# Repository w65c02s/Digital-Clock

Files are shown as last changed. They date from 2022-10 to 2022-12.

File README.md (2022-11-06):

## Digital Clock

### Introduction 
This is a clock is based on 74xx series TTL logic ICs. The clock pulse is generated by a 32.768kHz crystal which is further divided by divider ICs and a 1Hz pulse is obtained. This pulse is used to drive the seconds, minutes and hour counters. The display is a simple 7 segment LED display driven by 7447 BCD to 7 segment decoder.

The schematics and PCB has been designed in KiCad. This repository contains the complete KiCad project files made in version 6.0 of KiCad.

Refer the documenatation for complete details

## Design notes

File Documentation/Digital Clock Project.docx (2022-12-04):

Digital Clock Project

Introduction

This project is based on the commonly available 74xx series logic ICs. I wanted to build a clock from basic logic gates instead of using a dedicated clock IC. This way wanted to understand digital logic design.

Design

1 Hz clock pulse is generated by a combination of 32Khz crystal, CD4060 (U1) and CD4013 (U2) CMOS ICs. The clock oscillator is built around the CD4060 and 32khz standard clock crystal. 32768 is divided by 14 by the divider built into CD4060. This is further divided by 2 by CD4013 D type flip flop and a 1 Hz pulse is got.

This pulse is fed to the clock input of first decade counter U3 and the output Q3 is fed to the clock input of the second decade counter U5. These two ICs constitute the seconds counter of the clock. The output is fed to two 7447 U4, U6 7 segment decoders which in turn drive the common anode 7 segment displays AFF1, AFF2.

AND Gate U15A is used to detect 60 seconds count and then reset U5 counter and also drive the minutes counter built with U7. The pulse is gated through a OR gate U16A which also has a minutes advance pulse input.

The minutes advance is built with pushbutton SW1 and switch debounce circuit using U17A 74LS14 schmitt trigger inverter.

This minute pulse is fed to the clock input of third decade counter U7 and the output Q3 is fed to the clock input of the fourth decade counter U9. These two ICs constitute the minutes counter of the clock. The output is fed to two 7447 U8, U10 7 segment decoders which in turn drive the common anode 7 segment displays AFF3, AFF4.

AND Gate U15B is used to detect 60 minutes count and then reset U9 counter and also drive the hour counter built with U11. The pulse is gated through a OR gate U16B which also has a hour advance pulse input.

The hour advance is built with pushbutton SW2 and switch debounce circuit using U17B 74LS14 schmitt trigger inverter.

This hour pulse is fed to the clock input of fifth decade counter U11 and the output Q3 is fed to the clock input of the sixth decade counter U13. These two ICs constitute the hour counter of the clock. The output is fed to two 7447 U12, U14 7 segment decoders which in turn drive the common anode 7 segment displays AFF5, AFF6.

AND Gate U15C is used to detect 24 hour count and then reset U13 counter

Seconds blinker is built with transistor T1 which drives two LEDs D3,D4. The input is taken from the 1 Hz clock generator.

The circuit is powered by 5 volts through a Barrel jack connector.

C6 to C22 are power bypass capacitors used to reduce switching noise at logic gates.

The schematics and PCB was designed using opensource Kicad application.

Parts List

Part ID | Description | Quantity

Semiconductors
U1 | CD4060 CMOS 14 stage ripple carry binary counter/divider and oscillator | 1
U2 | CD4013 CMOS Dual D-Type Flip-Flop | 2
U3, U5, U7, U9, U11, U13 | 74LS90 Decade counter | 6
U4, U6, U8, U10, U12, U14 | 74LS47 BCD to 7 segment decoder | 6
U15 | 74LS08 Quad 2-input AND Gate | 1
U16 | 74LS32 Quad 2-input OR Gate | 1
U17 | 74LS14 Hex Schmitt-Trigger Inverters | 1
T1 | 2N2222 NPN transistor | 1
D1, D2 | 1N4148 small signal diode | 2
D3, D4 | Red LED 3mm | 2

Resistors (All ¼ watt)
R1 | 220K ohm resistor | 1
R2 | 10M ohm resistor | 1
R3, R5 | 5.1K ohm resistor | 2
R4, R6 | 2.2K ohm resistor | 2
R7 | 10K ohm resistor | 1
R8, R9, R10, R11, R12, R13, R14, R15, R16, R17, R18, R19, R20, R21, R22, R23, R24, R25, R26, R27, R28, R29, R30, R31, R32, R33, R34, R35, R36, R37, R38, R39, R40, R41, R42, R43, R44, R45, R46, R47, R48, R49 | 220 ohm resistor | 42

Capacitors
C1, C2 | 33pf ceramic capacitor | 2
C3, C4 | 4.7uf electrolytic capacitor | 2
C5 | 10uf electrolytic capacitor | 1
C6, C7, C8, C9, C10, C11, C12, C13, C14, C15, C16, C17, C18, C19, C20, C21, C22 | 0.1uf ceramic capacitor | 17
Miscellaneous
AFF1, AFF2, AFF3, AFF4, AFF5, AFF6 | 7 segment common anode display 0.56 inch | 6
J1 | Barrel Jack 2.1x5.5mm | 1
SW1, SW2 | Tactile switches 6mm | 2
X1 | 32Khz Crystal | 1

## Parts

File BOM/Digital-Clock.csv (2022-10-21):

Source: | E:\Clock Project\Digital-Clock\Digital-Clock.kicad_sch
Date: | 19-10-2022 21:15
Tool: | Eeschema (6.0.8)
Generator: | E:\Program Files\KiCad\6.0\bin\scripting\plugins/bom_csv_grouped_by_value.py
Component Count: | 103
Individual Components:
Item | Qty | Reference(s) | Value | LibPart | Footprint | Datasheet
 |  | AFF1 | LTS-6960HR | Display_Character:LTS-6960HR | Display_7Segment:7SegmentLED_LTS6760_LTS6780 | https://datasheet.octopart.com/LTS-6960HR-Lite-On-datasheet-11803242.pdf
 |  | AFF2 | LTS-6960HR | Display_Character:LTS-6960HR | Display_7Segment:7SegmentLED_LTS6760_LTS6780 | https://datasheet.octopart.com/LTS-6960HR-Lite-On-datasheet-11803242.pdf
 |  | AFF3 | LTS-6960HR | Display_Character:LTS-6960HR | Display_7Segment:7SegmentLED_LTS6760_LTS6780 | https://datasheet.octopart.com/LTS-6960HR-Lite-On-datasheet-11803242.pdf
 |  | AFF4 | LTS-6960HR | Display_Character:LTS-6960HR | Display_7Segment:7SegmentLED_LTS6760_LTS6780 | https://datasheet.octopart.com/LTS-6960HR-Lite-On-datasheet-11803242.pdf
 |  | AFF5 | LTS-6960HR | Display_Character:LTS-6960HR | Display_7Segment:7SegmentLED_LTS6760_LTS6780 | https://datasheet.octopart.com/LTS-6960HR-Lite-On-datasheet-11803242.pdf
 |  | AFF6 | LTS-6960HR | Display_Character:LTS-6960HR | Display_7Segment:7SegmentLED_LTS6760_LTS6780 | https://datasheet.octopart.com/LTS-6960HR-Lite-On-datasheet-11803242.pdf
 |  | C1 | 39p | Device:C | Capacitor_THT:C_Disc_D5.0mm_W2.5mm_P2.50mm | ~
 |  | C2 | 39p | Device:C | Capacitor_THT:C_Disc_D5.0mm_W2.5mm_P2.50mm | ~
 |  | C3 | 4.7u | Digital-Clock-rescue:CP-Device | Capacitor_THT:CP_Radial_D5.0mm_P2.50mm
 |  | C4 | 4.7u | Digital-Clock-rescue:CP-Device | Capacitor_THT:CP_Radial_D5.0mm_P2.50mm
 |  | C5 | 10u | Digital-Clock-rescue:CP-Device | Capacitor_THT:CP_Radial_D5.0mm_P2.50mm
 |  | C6 | 0.1u | Device:C | Capacitor_THT:C_Disc_D5.0mm_W2.5mm_P2.50mm | ~
 |  | C7 | 0.1u | Device:C | Capacitor_THT:C_Disc_D5.0mm_W2.5mm_P2.50mm | ~
 |  | C8 | 0.1u | Device:C | Capacitor_THT:C_Disc_D5.0mm_W2.5mm_P2.50mm | ~
 |  | C9 | 0.1u | Device:C | Capacitor_THT:C_Disc_D5.0mm_W2.5mm_P2.50mm | ~
 |  | C10 | 0.1u | Device:C | Capacitor_THT:C_Disc_D5.0mm_W2.5mm_P2.50mm | ~
 |  | C11 | 0.1u | Device:C | Capacitor_THT:C_Disc_D5.0mm_W2.5mm_P2.50mm | ~
 |  | C12 | 0.1u | Device:C | Capacitor_THT:C_Disc_D5.0mm_W2.5mm_P2.50mm | ~
 |  | C13 | 0.1u | Device:C | Capacitor_THT:C_Disc_D5.0mm_W2.5mm_P2.50mm | ~
 |  | C14 | 0.1u | Device:C | Capacitor_THT:C_Disc_D5.0mm_W2.5mm_P2.50mm | ~
 |  | C15 | 0.1u | Device:C | Capacitor_THT:C_Disc_D5.0mm_W2.5mm_P2.50mm | ~
 |  | C16 | 0.1u | Device:C | Capacitor_THT:C_Disc_D5.0mm_W2.5mm_P2.50mm | ~
 |  | C17 | 0.1u | Device:C | Capacitor_THT:C_Disc_D5.0mm_W2.5mm_P2.50mm | ~
 |  | C18 | 0.1u | Device:C | Capacitor_THT:C_Disc_D5.0mm_W2.5mm_P2.50mm | ~
 |  | C19 | 0.1u | Device:C | Capacitor_THT:C_Disc_D5.0mm_W2.5mm_P2.50mm | ~
 |  | C20 | 0.1u | Device:C | Capacitor_THT:C_Disc_D5.0mm_W2.5mm_P2.50mm | ~
 |  | C21 | 0.1u | Device:C | Capacitor_THT:C_Disc_D5.0mm_W2.5mm_P2.50mm | ~
 |  | C22 | 0.1u | Device:C | Capacitor_THT:C_Disc_D5.0mm_W2.5mm_P2.50mm | ~
 |  | D1 | 1N4148 | Diode:1N4148 | Diode_THT:D_DO-35_SOD27_P7.62mm_Horizontal | https://assets.nexperia.com/documents/data-sheet/1N4148_1N4448.pdf
 |  | D2 | 1N4148 | Diode:1N4148 | Diode_THT:D_DO-35_SOD27_P7.62mm_Horizontal | https://assets.nexperia.com/documents/data-sheet/1N4148_1N4448.pdf
 |  | D3 | LED | Device:LED | LED_THT:LED_D3.0mm | ~
 |  | D4 | LED | Device:LED | LED_THT:LED_D3.0mm | ~
 |  | J1 | Barrel_Jack_MountingPin | Connector:Barrel_Jack_MountingPin | Connector_BarrelJack:BarrelJack_CUI_PJ-063AH_Horizontal | ~
 |  | R1 | 220K | Device:R | Resistor_THT:R_Axial_DIN0207_L6.3mm_D2.5mm_P10.16mm_Horizontal | ~
 |  | R2 | 10M | Device:R | Resistor_THT:R_Axial_DIN0207_L6.3mm_D2.5mm_P10.16mm_Horizontal | ~
 |  | R3 | 5K | Device:R | Resistor_THT:R_Axial_DIN0207_L6.3mm_D2.5mm_P10.16mm_Horizontal | ~
 |  | R4 | 2.2K | Device:R | Resistor_THT:R_Axial_DIN0207_L6.3mm_D2.5mm_P10.16mm_Horizontal | ~
 |  | R5 | 5K | Device:R | Resistor_THT:R_Axial_DIN0207_L6.3mm_D2.5mm_P10.16mm_Horizontal | ~
 |  | R6 | 2.2K | Device:R | Resistor_THT:R_Axial_DIN0207_L6.3mm_D2.5mm_P10.16mm_Horizontal | ~
 |  | R7 | 10K | Device:R | Resistor_THT:R_Axial_DIN0207_L6.3mm_D2.5mm_P10.16mm_Horizontal | ~
 |  | R8 | 220 | Device:R | Resistor_THT:R_Axial_DIN0207_L6.3mm_D2.5mm_P10.16mm_Horizontal | ~
 |  | R9 | 220 | Device:R | Resistor_THT:R_Axial_DIN0207_L6.3mm_D2.5mm_P10.16mm_Horizontal | ~
 |  | R10 | 220 | Device:R | Resistor_THT:R_Axial_DIN0207_L6.3mm_D2.5mm_P10.16mm_Horizontal | ~
 |  | R11 | 220 | Device:R | Resistor_THT:R_Axial_DIN0207_L6.3mm_D2.5mm_P10.16mm_Horizontal | ~
 |  | R12 | 220 | Device:R | Resistor_THT:R_Axial_DIN0207_L6.3mm_D2.5mm_P10.16mm_Horizontal | ~
 |  | R13 | 220 | Device:R | Resistor_THT:R_Axial_DIN0207_L6.3mm_D2.5mm_P10.16mm_Horizontal | ~
 |  | R14 | 220 | Device:R | Resistor_THT:R_Axial_DIN0207_L6.3mm_D2.5mm_P10.16mm_Horizontal | ~
 |  | R15 | 220 | Device:R | Resistor_THT:R_Axial_DIN0207_L6.3mm_D2.5mm_P10.16mm_Horizontal | ~
 |  | R16 | 220 | Device:R | Resistor_THT:R_Axial_DIN0207_L6.3mm_D2.5mm_P10.16mm_Horizontal | ~
 |  | R17 | 220 | Device:R | Resistor_THT:R_Axial_DIN0207_L6.3mm_D2.5mm_P10.16mm_Horizontal | ~
 |  | R18 | 220 | Device:R | Resistor_THT:R_Axial_DIN0207_L6.3mm_D2.5mm_P10.16mm_Horizontal | ~
 |  | R19 | 220 | Device:R | Resistor_THT:R_Axial_DIN0207_L6.3mm_D2.5mm_P10.16mm_Horizontal | ~
 |  | R20 | 220 | Device:R | Resistor_THT:R_Axial_DIN0207_L6.3mm_D2.5mm_P10.16mm_Horizontal | ~
 |  | R21 | 220 | Device:R | Resistor_THT:R_Axial_DIN0207_L6.3mm_D2.5mm_P10.16mm_Horizontal | ~
 |  | R22 | 220 | Device:R | Resistor_THT:R_Axial_DIN0207_L6.3mm_D2.5mm_P10.16mm_Horizontal | ~
 |  | R23 | 220 | Device:R | Resistor_THT:R_Axial_DIN0207_L6.3mm_D2.5mm_P10.16mm_Horizontal | ~
 |  | R24 | 220 | Device:R | Resistor_THT:R_Axial_DIN0207_L6.3mm_D2.5mm_P10.16mm_Horizontal | ~
 |  | R25 | 220 | Device:R | Resistor_THT:R_Axial_DIN0207_L6.3mm_D2.5mm_P10.16mm_Horizontal | ~
 |  | R26 | 220 | Device:R | Resistor_THT:R_Axial_DIN0207_L6.3mm_D2.5mm_P10.16mm_Horizontal | ~
 |  | R27 | 220 | Device:R | Resistor_THT:R_Axial_DIN0207_L6.3mm_D2.5mm_P10.16mm_Horizontal | ~
 |  | R28 | 220 | Device:R | Resistor_THT:R_Axial_DIN0207_L6.3mm_D2.5mm_P10.16mm_Horizontal | ~
 |  | R29 | 220 | Device:R | Resistor_THT:R_Axial_DIN0207_L6.3mm_D2.5mm_P10.16mm_Horizontal | ~
 |  | R30 | 220 | Device:R | Resistor_THT:R_Axial_DIN0207_L6.3mm_D2.5mm_P10.16mm_Horizontal | ~
 |  | R31 | 220 | Device:R | Resistor_THT:R_Axial_DIN0207_L6.3mm_D2.5mm_P10.16mm_Horizontal | ~
 |  | R32 | 220 | Device:R | Resistor_THT:R_Axial_DIN0207_L6.3mm_D2.5mm_P10.16mm_Horizontal | ~
 |  | R33 | 220 | Device:R | Resistor_THT:R_Axial_DIN0207_L6.3mm_D2.5mm_P10.16mm_Horizontal | ~
 |  | R34 | 220 | Device:R | Resistor_THT:R_Axial_DIN0207_L6.3mm_D2.5mm_P10.16mm_Horizontal | ~
 |  | R35 | 220 | Device:R | Resistor_THT:R_Axial_DIN0207_L6.3mm_D2.5mm_P10.16mm_Horizontal | ~
 |  | R36 | 220 | Device:R | Resistor_THT:R_Axial_DIN0207_L6.3mm_D2.5mm_P10.16mm_Horizontal | ~
 |  | R37 | 220 | Device:R | Resistor_THT:R_Axial_DIN0207_L6.3mm_D2.5mm_P10.16mm_Horizontal | ~
 |  | R38 | 220 | Device:R | Resistor_THT:R_Axial_DIN0207_L6.3mm_D2.5mm_P10.16mm_Horizontal | ~
 |  | R39 | 220 | Device:R | Resistor_THT:R_Axial_DIN0207_L6.3mm_D2.5mm_P10.16mm_Horizontal | ~
 |  | R40 | 220 | Device:R | Resistor_THT:R_Axial_DIN0207_L6.3mm_D2.5mm_P10.16mm_Horizontal | ~
 |  | R41 | 220 | Device:R | Resistor_THT:R_Axial_DIN0207_L6.3mm_D2.5mm_P10.16mm_Horizontal | ~
 |  | R42 | 220 | Device:R | Resistor_THT:R_Axial_DIN0207_L6.3mm_D2.5mm_P10.16mm_Horizontal | ~
 |  | R43 | 220 | Device:R | Resistor_THT:R_Axial_DIN0207_L6.3mm_D2.5mm_P10.16mm_Horizontal | ~
 |  | R44 | 220 | Device:R | Resistor_THT:R_Axial_DIN0207_L6.3mm_D2.5mm_P10.16mm_Horizontal | ~
 |  | R45 | 220 | Device:R | Resistor_THT:R_Axial_DIN0207_L6.3mm_D2.5mm_P10.16mm_Horizontal | ~
 |  | R46 | 220 | Device:R | Resistor_THT:R_Axial_DIN0207_L6.3mm_D2.5mm_P10.16mm_Horizontal | ~
 |  | R47 | 220 | Device:R | Resistor_THT:R_Axial_DIN0207_L6.3mm_D2.5mm_P10.16mm_Horizontal | ~
 |  | R48 | 220 | Device:R | Resistor_THT:R_Axial_DIN0207_L6.3mm_D2.5mm_P10.16mm_Horizontal | ~
 |  | R49 | 220 | Device:R | Resistor_THT:R_Axial_DIN0207_L6.3mm_D2.5mm_P10.16mm_Horizontal | ~
 |  | SW1 | SW_Push | Switch:SW_Push | Button_Switch_THT:SW_PUSH_6mm | ~
 |  | SW2 | SW_Push | Switch:SW_Push | Button_Switch_THT:SW_PUSH_6mm | ~
 |  | T1 | 2N2222 | Transistor_BJT:2N2219 | Package_TO_SOT_THT:TO-92 | http://www.onsemi.com/pub_link/Collateral/2N2219-D.PDF
 |  | U1 | CD4060 | Digital-Clock-rescue:CD4060-CD4060 | Package_DIP:DIP-16_W7.62mm | DOCUMENTATION
 |  | U2 | 4013 | 4xxx:4013 | Package_DIP:DIP-14_W7.62mm | http://www.onsemi.com/pub/Collateral/MC14013B-D.PDF
 |  | U3 | 74LS90 | 74xx:74LS90 | Package_DIP:DIP-14_W7.62mm | http://www.ti.com/lit/gpn/sn74LS90
 |  | U4 | 74LS47 | 74xx:74LS47 | Package_DIP:DIP-16_W7.62mm | http://www.ti.com/lit/gpn/sn74LS47
 |  | U5 | 74LS90 | 74xx:74LS90 | Package_DIP:DIP-14_W7.62mm | http://www.ti.com/lit/gpn/sn74LS90
 |  | U6 | 74LS47 | 74xx:74LS47 | Package_DIP:DIP-16_W7.62mm | http://www.ti.com/lit/gpn/sn74LS47
 |  | U7 | 74LS90 | 74xx:74LS90 | Package_DIP:DIP-14_W7.62mm | http://www.ti.com/lit/gpn/sn74LS90
 |  | U8 | 74LS47 | 74xx:74LS47 | Package_DIP:DIP-16_W7.62mm | http://www.ti.com/lit/gpn/sn74LS47
 |  | U9 | 74LS90 | 74xx:74LS90 | Package_DIP:DIP-14_W7.62mm | http://www.ti.com/lit/gpn/sn74LS90
 |  | U10 | 74LS47 | 74xx:74LS47 | Package_DIP:DIP-16_W7.62mm | http://www.ti.com/lit/gpn/sn74LS47
 |  | U11 | 74LS90 | 74xx:74LS90 | Package_DIP:DIP-14_W7.62mm | http://www.ti.com/lit/gpn/sn74LS90
 |  | U12 | 74LS47 | 74xx:74LS47 | Package_DIP:DIP-16_W7.62mm | http://www.ti.com/lit/gpn/sn74LS47
 |  | U13 | 74LS90 | 74xx:74LS90 | Package_DIP:DIP-14_W7.62mm | http://www.ti.com/lit/gpn/sn74LS90
 |  | U14 | 74LS47 | 74xx:74LS47 | Package_DIP:DIP-16_W7.62mm | http://www.ti.com/lit/gpn/sn74LS47
 |  | U15 | 74LS08 | 74xx:74LS08 | Package_DIP:DIP-14_W7.62mm | http://www.ti.com/lit/gpn/sn74LS08
 |  | U16 | 74LS32 | 74xx:74LS32 | Package_DIP:DIP-14_W7.62mm | http://www.ti.com/lit/gpn/sn74LS32
 |  | U17 | 74LS14 | 74xx:74LS14 | Package_DIP:DIP-14_W7.62mm | http://www.ti.com/lit/gpn/sn74LS14
 |  | X1 | 32Khz | Device:Crystal | Crystal:Crystal_Round_D1.0mm_Vertical | ~
Collated Components:
Item | Qty | Reference(s) | Value | LibPart | Footprint | Datasheet
1 | 6 | AFF1, AFF2, AFF3, AFF4, AFF5, AFF6 | LTS-6960HR | Display_Character:LTS-6960HR | Display_7Segment:7SegmentLED_LTS6760_LTS6780 | https://datasheet.octopart.com/LTS-6960HR-Lite-On-datasheet-11803242.pdf
2 | 2 | C1, C2 | 39p | Device:C | Capacitor_THT:C_Disc_D5.0mm_W2.5mm_P2.50mm | ~
3 | 2 | C3, C4 | 4.7u | Digital-Clock-rescue:CP-Device | Capacitor_THT:CP_Radial_D5.0mm_P2.50mm
4 | 1 | C5 | 10u | Digital-Clock-rescue:CP-Device | Capacitor_THT:CP_Radial_D5.0mm_P2.50mm
5 | 17 | C6, C7, C8, C9, C10, C11, C12, C13, C14, C15, C16, C17, C18, C19, C20, C21, C22 | 0.1u | Device:C | Capacitor_THT:C_Disc_D5.0mm_W2.5mm_P2.50mm | ~
6 | 2 | D1, D2 | 1N4148 | Diode:1N4148 | Diode_THT:D_DO-35_SOD27_P7.62mm_Horizontal | https://assets.nexperia.com/documents/data-sheet/1N4148_1N4448.pdf
7 | 2 | D3, D4 | LED | Device:LED | LED_THT:LED_D3.0mm | ~
8 | 1 | J1 | Barrel_Jack_MountingPin | Connector:Barrel_Jack_MountingPin | Connector_BarrelJack:BarrelJack_CUI_PJ-063AH_Horizontal | ~
9 | 1 | R1 | 220K | Device:R | Resistor_THT:R_Axial_DIN0207_L6.3mm_D2.5mm_P10.16mm_Horizontal | ~
10 | 1 | R2 | 10M | Device:R | Resistor_THT:R_Axial_DIN0207_L6.3mm_D2.5mm_P10.16mm_Horizontal | ~
11 | 2 | R3, R5 | 5K | Device:R | Resistor_THT:R_Axial_DIN0207_L6.3mm_D2.5mm_P10.16mm_Horizontal | ~
12 | 2 | R4, R6 | 2.2K | Device:R | Resistor_THT:R_Axial_DIN0207_L6.3mm_D2.5mm_P10.16mm_Horizontal | ~
13 | 1 | R7 | 10K | Device:R | Resistor_THT:R_Axial_DIN0207_L6.3mm_D2.5mm_P10.16mm_Horizontal | ~
14 | 42 | R8, R9, R10, R11, R12, R13, R14, R15, R16, R17, R18, R19, R20, R21, R22, R23, R24, R25, R26, R27, R28, R29, R30, R31, R32, R33, R34, R35, R36, R37, R38, R39, R40, R41, R42, R43, R44, R45, R46, R47, R48, R49 | 220 | Device:R | Resistor_THT:R_Axial_DIN0207_L6.3mm_D2.5mm_P10.16mm_Horizontal | ~
15 | 2 | SW1, SW2 | SW_Push | Switch:SW_Push | Button_Switch_THT:SW_PUSH_6mm | ~
16 | 1 | T1 | 2N2222 | Transistor_BJT:2N2219 | Package_TO_SOT_THT:TO-92 | http://www.onsemi.com/pub_link/Collateral/2N2219-D.PDF
17 | 1 | U1 | CD4060 | Digital-Clock-rescue:CD4060-CD4060 | Package_DIP:DIP-16_W7.62mm | DOCUMENTATION
18 | 1 | U2 | 4013 | 4xxx:4013 | Package_DIP:DIP-14_W7.62mm | http://www.onsemi.com/pub/Collateral/MC14013B-D.PDF
19 | 6 | U3, U5, U7, U9, U11, U13 | 74LS90 | 74xx:74LS90 | Package_DIP:DIP-14_W7.62mm | http://www.ti.com/lit/gpn/sn74LS90
20 | 6 | U4, U6, U8, U10, U12, U14 | 74LS47 | 74xx:74LS47 | Package_DIP:DIP-16_W7.62mm | http://www.ti.com/lit/gpn/sn74LS47
21 | 1 | U15 | 74LS08 | 74xx:74LS08 | Package_DIP:DIP-14_W7.62mm | http://www.ti.com/lit/gpn/sn74LS08
22 | 1 | U16 | 74LS32 | 74xx:74LS32 | Package_DIP:DIP-14_W7.62mm | http://www.ti.com/lit/gpn/sn74LS32
23 | 1 | U17 | 74LS14 | 74xx:74LS14 | Package_DIP:DIP-14_W7.62mm | http://www.ti.com/lit/gpn/sn74LS14
24 | 1 | X1 | 32Khz | Device:Crystal | Crystal:Crystal_Round_D1.0mm_Vertical | ~

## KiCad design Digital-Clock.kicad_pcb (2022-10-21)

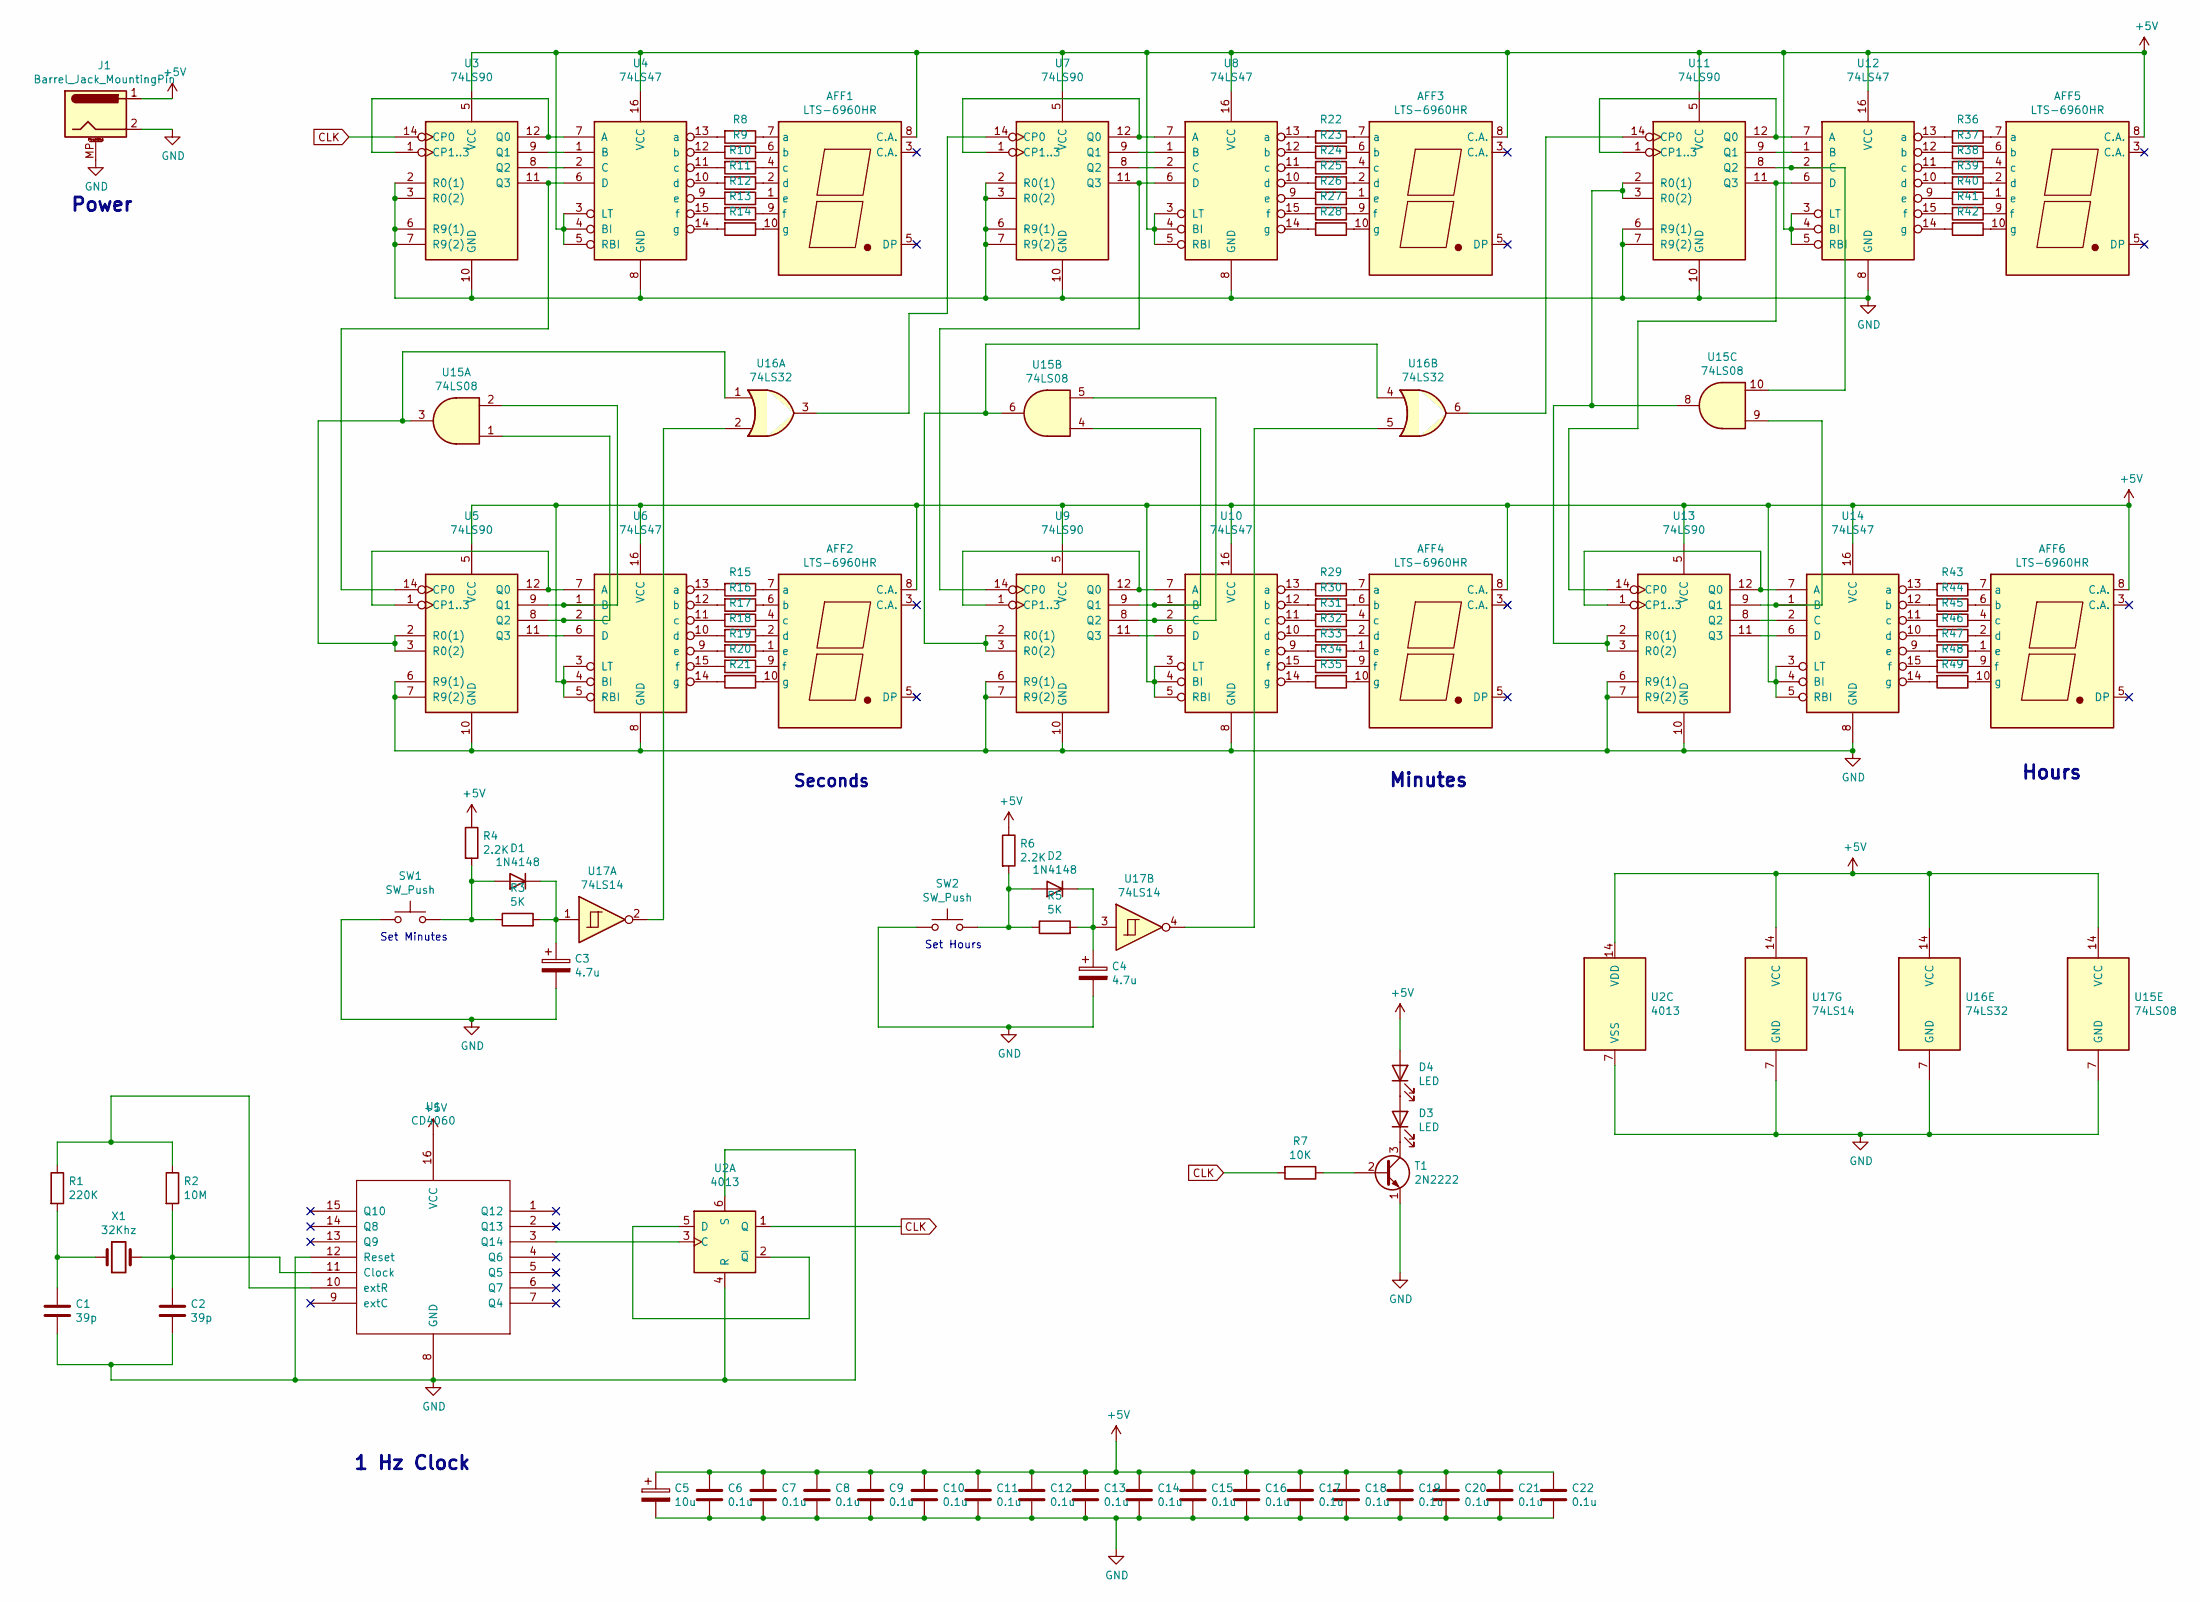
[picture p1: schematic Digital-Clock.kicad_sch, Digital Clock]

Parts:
AFF1, AFF2, AFF3, AFF4, AFF5, AFF6: LTS-6960HR; 7SegmentLED_LTS6760_LTS6780
C1, C2: 39p; C_Disc_D5.0mm_W2.5mm_P2.50mm
C3, C4: 4.7u; CP_Radial_D5.0mm_P2.50mm
C5: 10u; CP_Radial_D5.0mm_P2.50mm
C6, C7, C8, C9, C10, C11, C12, C13, C14, C15, C16, C17, C18, C19, C20, C21, C22: 0.1u; C_Disc_D5.0mm_W2.5mm_P2.50mm
D1, D2: 1N4148; D_DO-35_SOD27_P7.62mm_Horizontal
D3, D4: LED; LED_D3.0mm
J1: Barrel_Jack_MountingPin; BarrelJack_CUI_PJ-063AH_Horizontal
R1: 220K; R_Axial_DIN0207_L6.3mm_D2.5mm_P10.16mm_Horizontal
R2: 10M; R_Axial_DIN0207_L6.3mm_D2.5mm_P10.16mm_Horizontal
R3, R5: 5K; R_Axial_DIN0207_L6.3mm_D2.5mm_P10.16mm_Horizontal
R4, R6: 2.2K; R_Axial_DIN0207_L6.3mm_D2.5mm_P10.16mm_Horizontal
R7: 10K; R_Axial_DIN0207_L6.3mm_D2.5mm_P10.16mm_Horizontal
R8, R9, R10, R11, R12, R13, R14, R15, R16, R17, R18, R19, R20, R21, R22, R23, R24, R25, R26, R27, R28, R29, R30, R31, R32, R33, R34, R35, R36, R37, R38, R39, R40, R41, R42, R43, R44, R45, R46, R47, R48, R49: 220; R_Axial_DIN0207_L6.3mm_D2.5mm_P10.16mm_Horizontal
SW1, SW2: SW_Push; SW_PUSH_6mm
T1: 2N2222; TO-92
U1: CD4060; DIP-16_W7.62mm
U2: 4013; DIP-14_W7.62mm
U3, U5, U7, U9, U11, U13: 74LS90; DIP-14_W7.62mm
U4, U6, U8, U10, U12, U14: 74LS47; DIP-16_W7.62mm
U15: 74LS08; DIP-14_W7.62mm
U16: 74LS32; DIP-14_W7.62mm
U17: 74LS14; DIP-14_W7.62mm
X1: 32Khz; Crystal_Round_D1.0mm_Vertical

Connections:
+5V: AFF1.8 (C.A.), AFF2.8 (C.A.), AFF3.8 (C.A.), AFF4.8 (C.A.), AFF5.8 (C.A.), AFF6.8 (C.A.), C5.1, C6.1, C7.1, C8.1, C9.1, C10.1, C11.1, C12.1, C13.1, C14.1, C15.1, C16.1, C17.1, C18.1, C19.1, C20.1, C21.1, C22.1, D4.2 (A), J1.1, R4.1, R6.1, U1.16 (VCC), U2.14 (VDD), U3.5 (VCC), U4.3 (LT), U4.4 (BI), U4.5 (RBI), U4.16 (VCC), U5.5 (VCC), U6.3 (LT), U6.4 (BI), U6.5 (RBI), U6.16 (VCC), U7.5 (VCC), U8.3 (LT), U8.4 (BI), U8.5 (RBI), U8.16 (VCC), U9.5 (VCC), U10.3 (LT), U10.4 (BI), U10.5 (RBI), U10.16 (VCC), U11.5 (VCC), U12.3 (LT), U12.4 (BI), U12.5 (RBI), U12.16 (VCC), U13.5 (VCC), U14.3 (LT), U14.4 (BI), U14.5 (RBI), U14.16 (VCC), U15.14 (VCC), U16.14 (VCC), U17.14 (VCC)
CLK: R7.2, U2.1 (Q), U3.14 (CP0)
GND: C1.2, C2.2, C3.2, C4.2, C5.2, C6.2, C7.2, C8.2, C9.2, C10.2, C11.2, C12.2, C13.2, C14.2, C15.2, C16.2, C17.2, C18.2, C19.2, C20.2, C21.2, C22.2, J1.2, J1.MP (MountPin), SW1.1, SW2.1, T1.1 (E), U1.8 (GND), U1.12 (Reset), U2.4 (R), U2.6 (S), U2.7 (VSS), U3.2 (R0(1)), U3.3 (R0(2)), U3.6 (R9(1)), U3.7 (R9(2)), U3.10 (GND), U4.8 (GND), U5.6 (R9(1)), U5.7 (R9(2)), U5.10 (GND), U6.8 (GND), U7.2 (R0(1)), U7.3 (R0(2)), U7.6 (R9(1)), U7.7 (R9(2)), U7.10 (GND), U8.8 (GND), U9.6 (R9(1)), U9.7 (R9(2)), U9.10 (GND), U10.8 (GND), U11.6 (R9(1)), U11.7 (R9(2)), U11.10 (GND), U12.8 (GND), U13.6 (R9(1)), U13.7 (R9(2)), U13.10 (GND), U14.8 (GND), U15.7 (GND), U16.7 (GND), U17.7 (GND)
unnamed: AFF1.1 (e), R12.1
unnamed: AFF1.2 (d), R11.1
unnamed: AFF1.4 (c), R10.1
unnamed: AFF1.6 (b), R9.1
unnamed: AFF1.7 (a), R8.1
unnamed: AFF1.9 (f), R13.1
unnamed: AFF1.10 (g), R14.1
unnamed: AFF2.1 (e), R19.1
unnamed: AFF2.2 (d), R18.1
unnamed: AFF2.4 (c), R17.1
unnamed: AFF2.6 (b), R16.1
unnamed: AFF2.7 (a), R15.1
unnamed: AFF2.9 (f), R20.1
unnamed: AFF2.10 (g), R21.1
unnamed: AFF3.1 (e), R26.1
unnamed: AFF3.2 (d), R25.1
unnamed: AFF3.4 (c), R24.1
unnamed: AFF3.6 (b), R23.1
unnamed: AFF3.7 (a), R22.1
unnamed: AFF3.9 (f), R27.1
unnamed: AFF3.10 (g), R28.1
unnamed: AFF4.1 (e), R33.1
unnamed: AFF4.2 (d), R32.1
unnamed: AFF4.4 (c), R31.1
unnamed: AFF4.6 (b), R30.1
unnamed: AFF4.7 (a), R29.1
unnamed: AFF4.9 (f), R34.1
unnamed: AFF4.10 (g), R35.1
unnamed: AFF5.1 (e), R40.1
unnamed: AFF5.2 (d), R39.1
unnamed: AFF5.4 (c), R38.1
unnamed: AFF5.6 (b), R37.1
unnamed: AFF5.7 (a), R36.1
unnamed: AFF5.9 (f), R41.1
unnamed: AFF5.10 (g), R42.1
unnamed: AFF6.1 (e), R47.1
unnamed: AFF6.2 (d), R46.1
unnamed: AFF6.4 (c), R45.1
unnamed: AFF6.6 (b), R44.1
unnamed: AFF6.7 (a), R43.1
unnamed: AFF6.9 (f), R48.1
unnamed: AFF6.10 (g), R49.1
unnamed: C1.1, R1.2, X1.1
unnamed: C2.1, R2.2, U1.11 (Clock), X1.2
unnamed: C3.1, D1.1 (K), R3.2, U17.1
unnamed: C4.1, D2.1 (K), R5.2, U17.3
unnamed: D1.2 (A), R3.1, R4.2, SW1.2
unnamed: D2.2 (A), R5.1, R6.2, SW2.2
unnamed: D3.1 (K), T1.3 (C)
unnamed: D3.2 (A), D4.1 (K)
unnamed: R1.1, R2.1, U1.10 (extR)
unnamed: R7.1, T1.2 (B)
unnamed: R8.2, U4.13 (a)
unnamed: R9.2, U4.12 (b)
unnamed: R10.2, U4.11 (c)
unnamed: R11.2, U4.10 (d)
unnamed: R12.2, U4.9 (e)
unnamed: R13.2, U4.15 (f)
unnamed: R14.2, U4.14 (g)
unnamed: R15.2, U6.13 (a)
unnamed: R16.2, U6.12 (b)
unnamed: R17.2, U6.11 (c)
unnamed: R18.2, U6.10 (d)
unnamed: R19.2, U6.9 (e)
unnamed: R20.2, U6.15 (f)
unnamed: R21.2, U6.14 (g)
unnamed: R22.2, U8.13 (a)
unnamed: R23.2, U8.12 (b)
unnamed: R24.2, U8.11 (c)
unnamed: R25.2, U8.10 (d)
unnamed: R26.2, U8.9 (e)
unnamed: R27.2, U8.15 (f)
unnamed: R28.2, U8.14 (g)
unnamed: R29.2, U10.13 (a)
unnamed: R30.2, U10.12 (b)
unnamed: R31.2, U10.11 (c)
unnamed: R32.2, U10.10 (d)
unnamed: R33.2, U10.9 (e)
unnamed: R34.2, U10.15 (f)
unnamed: R35.2, U10.14 (g)
unnamed: R36.2, U12.13 (a)
unnamed: R37.2, U12.12 (b)
unnamed: R38.2, U12.11 (c)
unnamed: R39.2, U12.10 (d)
unnamed: R40.2, U12.9 (e)
unnamed: R41.2, U12.15 (f)
unnamed: R42.2, U12.14 (g)
unnamed: R43.2, U14.13 (a)
unnamed: R44.2, U14.12 (b)
unnamed: R45.2, U14.11 (c)
unnamed: R46.2, U14.10 (d)
unnamed: R47.2, U14.9 (e)
unnamed: R48.2, U14.15 (f)
unnamed: R49.2, U14.14 (g)
unnamed: U1.3 (Q14), U2.3 (C)
unnamed: U2.2 (~Q), U2.5 (D)
unnamed: U3.1 (CP1..3), U3.12 (Q0), U4.7 (A)
unnamed: U3.8 (Q2), U4.2 (C)
unnamed: U3.9 (Q1), U4.1 (B)
unnamed: U3.11 (Q3), U4.6 (D), U5.14 (CP0)
unnamed: U5.1 (CP1..3), U5.12 (Q0), U6.7 (A)
unnamed: U5.11 (Q3), U6.6 (D)
unnamed: U7.1 (CP1..3), U7.12 (Q0), U8.7 (A)
unnamed: U7.8 (Q2), U8.2 (C)
unnamed: U7.9 (Q1), U8.1 (B)
unnamed: U7.11 (Q3), U8.6 (D), U9.14 (CP0)
unnamed: U9.9 (Q1), U10.1 (B), U15.4
unnamed: U9.8 (Q2), U10.2 (C), U15.5
unnamed: U9.11 (Q3), U10.6 (D)
unnamed: U9.1 (CP1..3), U9.12 (Q0), U10.7 (A)
unnamed: U11.1 (CP1..3), U11.12 (Q0), U12.7 (A)
unnamed: U11.2 (R0(1)), U11.3 (R0(2)), U13.2 (R0(1)), U13.3 (R0(2)), U15.8
unnamed: U11.8 (Q2), U12.2 (C), U15.10
unnamed: U11.9 (Q1), U12.1 (B)
unnamed: U11.11 (Q3), U12.6 (D), U13.14 (CP0)
unnamed: U11.14 (CP0), U16.6
unnamed: U13.1 (CP1..3), U13.12 (Q0), U14.7 (A)
unnamed: U13.8 (Q2), U14.2 (C)
unnamed: U13.9 (Q1), U14.1 (B), U15.9
unnamed: U13.11 (Q3), U14.6 (D)
unnamed: U5.8 (Q2), U6.2 (C), U15.1
unnamed: U5.9 (Q1), U6.1 (B), U15.2
unnamed: U5.2 (R0(1)), U5.3 (R0(2)), U15.3, U16.1
unnamed: U9.2 (R0(1)), U9.3 (R0(2)), U15.6, U16.4
unnamed: U16.2, U17.2
unnamed: U7.14 (CP0), U16.3
unnamed: U16.5, U17.4

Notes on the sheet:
Minutes
Set Hours
Seconds
Hours
1 Hz Clock
Set Minutes
Power

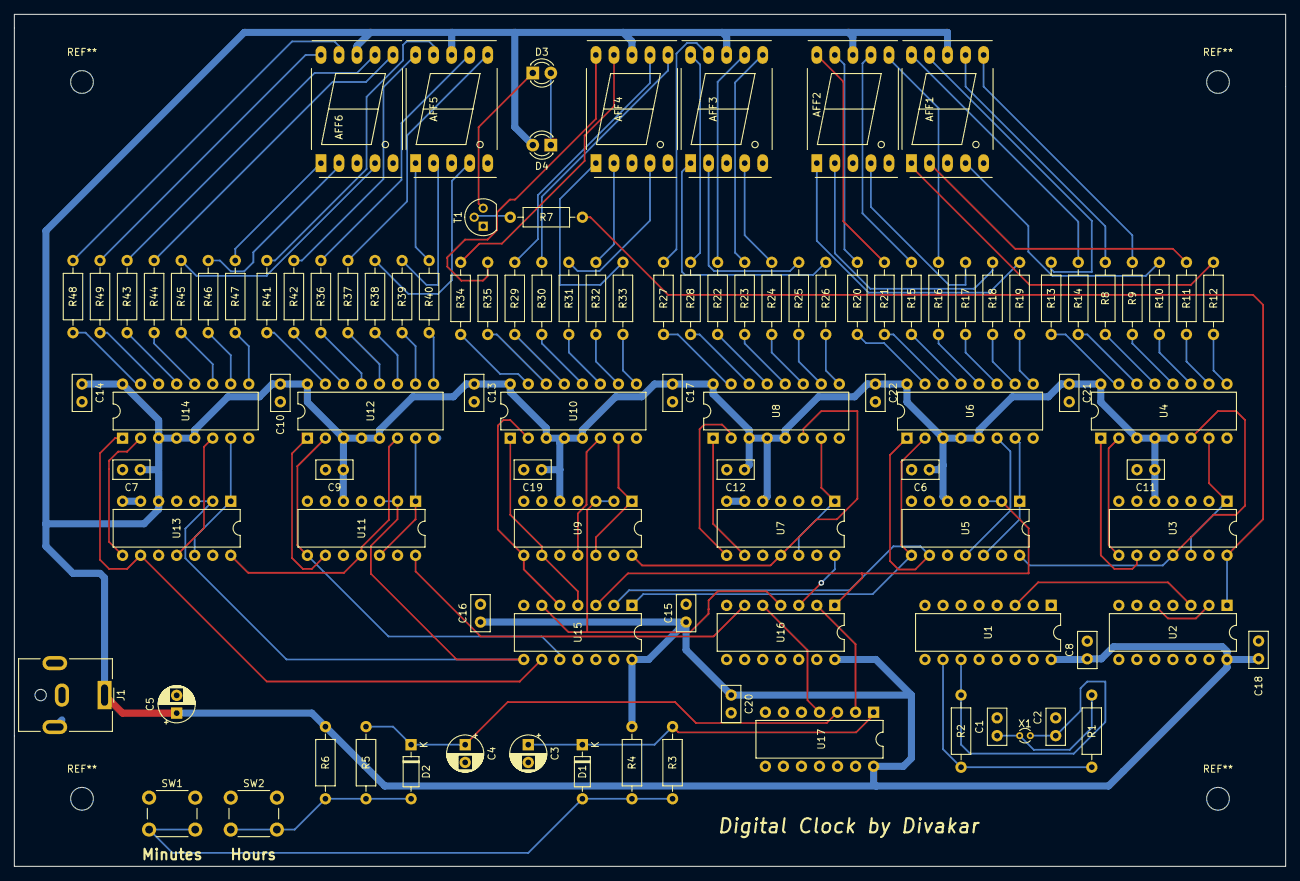
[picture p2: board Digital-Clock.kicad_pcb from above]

Board: 2 copper layers, 179.1 x 120.0 mm, 103 parts (0 on the bottom side), 130 nets.
